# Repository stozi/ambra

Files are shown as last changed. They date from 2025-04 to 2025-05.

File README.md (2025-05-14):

# Ambra
A [Kalmar](https://github.com/aroum/kalmar)/[A. Dux](https://github.com/tapioki/cephalopoda/tree/main/Architeuthis%20dux)-based 34-key split ortho keyboard. [ZMK shield](https://github.com/stozi/zmk-keyboard-ambra)

### Included from Kalmar

- power switch
- reset button
- solder jumpers to mount the MCU the same way on both sides
- perforations on the tab for the connector between the right & left boards

### Changes from Kalmar

- thumb keys mount at 90° with pogo pins and 3D-printed magnet brackets
- besides Kailh Choc, support for Gateron KS-33, both hotswap only
- JST PH battery connector
- Switched the TRRS jack to the same pogo pin connector used for the thumb keys to prevent shorting (VCC/power is the middle pin so mounting one side backwards won't cause damage)
- ground plane for some ESD protection, new pinout

If you don't need fold-down packability or can't get the magnets, you can run a 9mm or longer M2 bolt through both brackets. However, any fall will then be more likely to cause damage.

Consider putting a non-conductive coating between the JST connector's mount points and the battery. Remove remnants of perforations on the thumb-key board before attaching the bracket. Personally, I solder the top-side jumpers to mount the MCUs component-side up so I can see the LEDs, and keep them safe under a case handcrafted from plumbing silicone.

Passed basic testing.

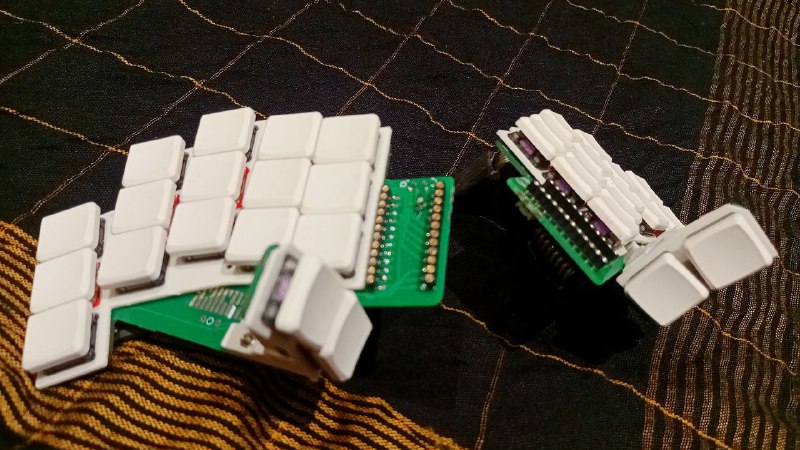
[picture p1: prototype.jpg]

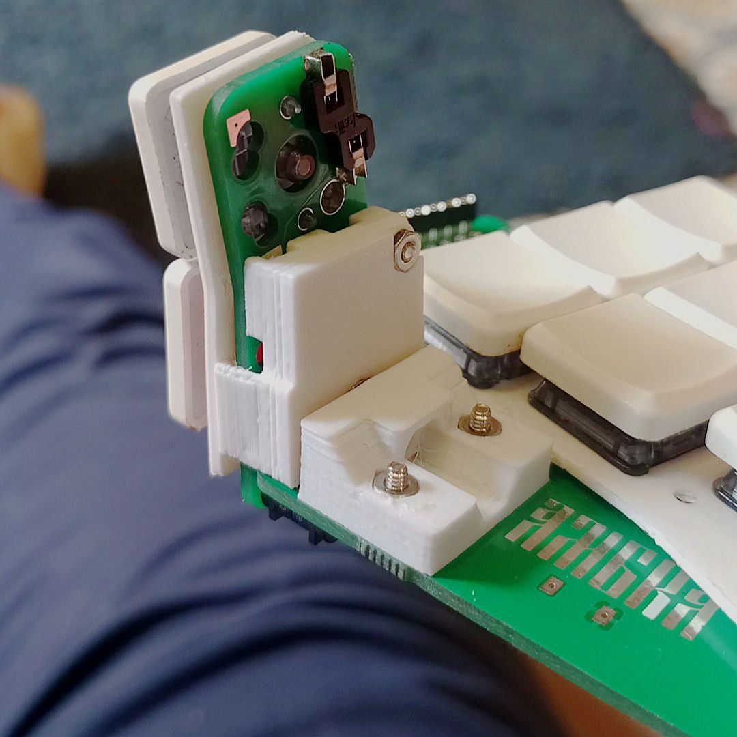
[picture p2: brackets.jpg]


## BOM

Item     | Qty   | Notes 
----------|-------|-------
[SuperMini NRF52840 MCU](https://www.aliexpress.com/item/1005008099333183.html) | 2 | inc. sockets. Alternatively, ProMicro/Elite-C for a wired build
[Kailh Choc V1](https://a.aliexpress.com/_EGNqHgc) | 34 | key switches. Alternatively, [Gateron KS-33](https://a.aliexpress.com/_EuUuYVU)
[Choc hotswap sockets](https://a.aliexpress.com/_Eu2JK5E) | 34 | Alternatively, [Gateron KS-33 hotswap sockets](https://a.aliexpress.com/_EGlN42e)
[Keycaps](https://a.aliexpress.com/_EGNqLfE) | 34 | 1U. If using KS-33 switches, STL files are provided to print your own 'MX stem, Choc-1U-spaced' caps
[Magnets](https://a.aliexpress.com/_EGMQ442) | 2 | D6×3mm annular cylinder
[RTLECS MG03254 3-pin](https://a.aliexpress.com/_Ev5QIZa) | 2 straight m, 2 90° f | magnetic pogo-pin connectors
[MSK-12CO2](https://aliexpress.ru/item/1005001398386692.html) | 2 | power switch
[SMD button 3×4×2](https://aliexpress.ru/item/1005003812819985.html) | 2 | reset switch
[301230 li-po](https://aliexpress.ru/item/32732458079.html) | 2 | battery
[JST PH right-angle 2-pin](https://www.aliexpress.com/item/1005008131930144.html) | 2 | battery connector
[JST wire](https://www.aliexpress.com/item/1005001649158434.html) | 2 | solder & shrink tube to battery wires, no crimping needed, or [battery already with connector](https://a.aliexpress.com/_EJkhjGm) 
[M3 machine screws, 3mm](https://www.aliexpress.com/item/1005006662972635.html) | 2 | flathead, couples with magnet
[M3 thin hex nuts](https://a.aliexpress.com/_EvCkuwM) | 2 |
[M2 tapered head machine screws, 7mm](https://a.aliexpress.com/_EzeQ9lA) | 2 | holds magnet
[M2 flat head machine screws, 8mm](https://www.aliexpress.com/item/1005006662972635.html) | 6 | for brackets
[M2 thin hex nuts](https://a.aliexpress.com/_EvCkuwM) | 8 |
OPTIONAL: [RTLECS MG03254 cable](https://www.aliexpress.com/item/1005007988032729.html) and extra RTLECS 90° female connectors as listed above | 2 of each | For a wired build: cut, solder and shrink-tube the two wires together

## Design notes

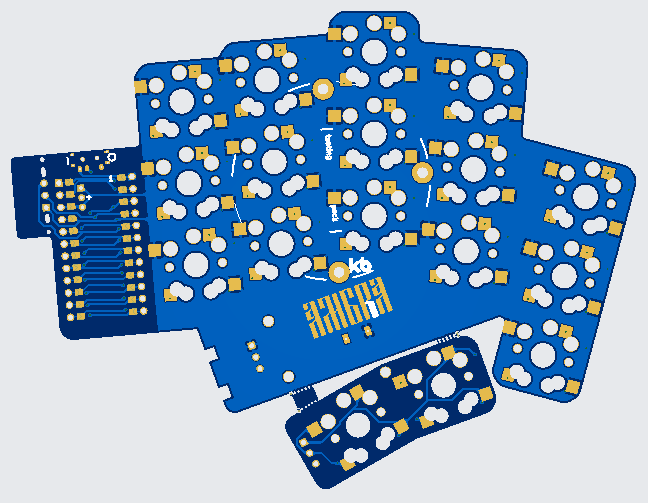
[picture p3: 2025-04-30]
ambra-back.png

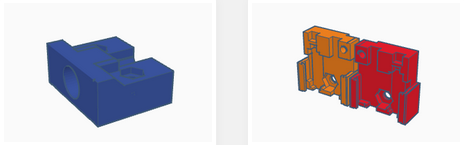
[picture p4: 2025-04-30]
brackets.png

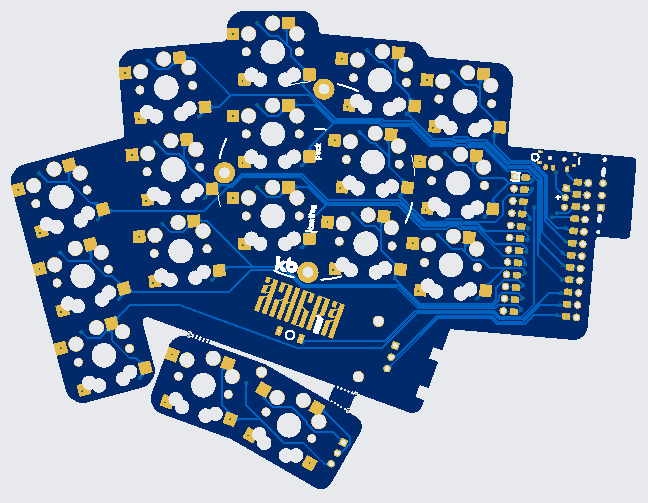
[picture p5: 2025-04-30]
ambra.png

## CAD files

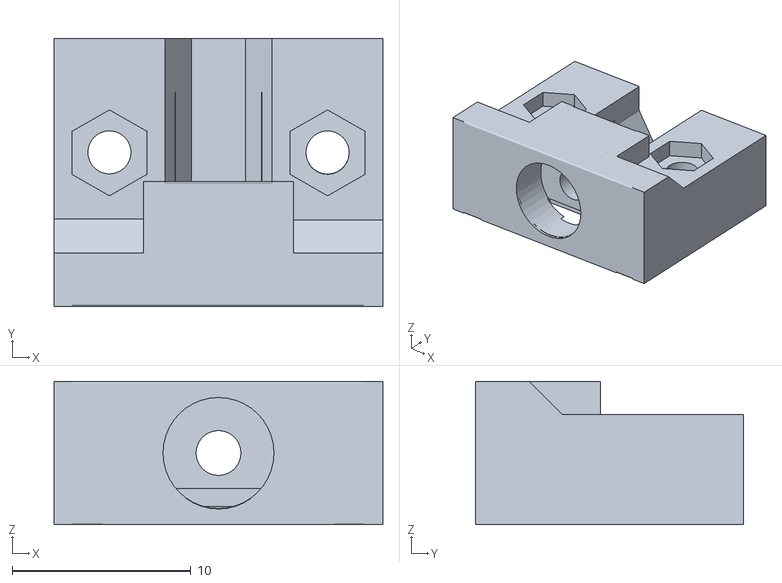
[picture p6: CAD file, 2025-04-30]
Ambra bracket board.stl
18.4 x 15.0 x 8.00

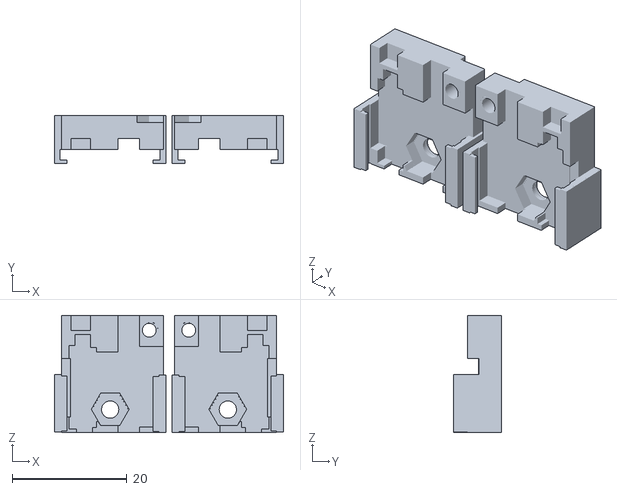
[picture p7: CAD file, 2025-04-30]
Ambra bracket thumb.stl
39.9 x 8.30 x 20.4

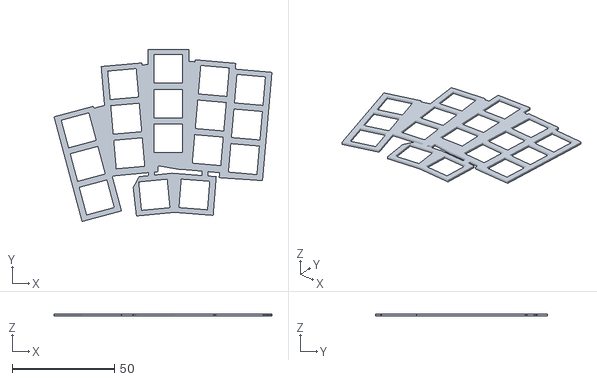
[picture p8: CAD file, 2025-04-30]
Ambra plate.stl
106.7 x 84.1 x 1.20

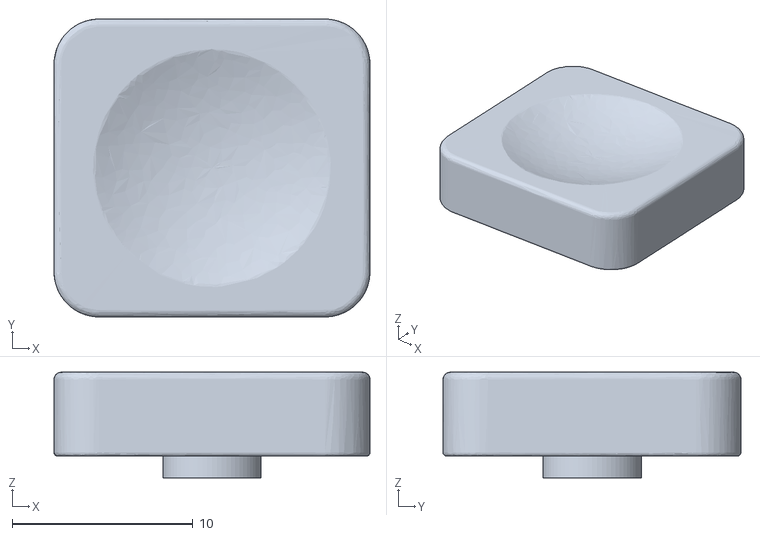
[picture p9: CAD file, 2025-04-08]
MX stem Choc U1.stl
17.5 x 16.5 x 5.85

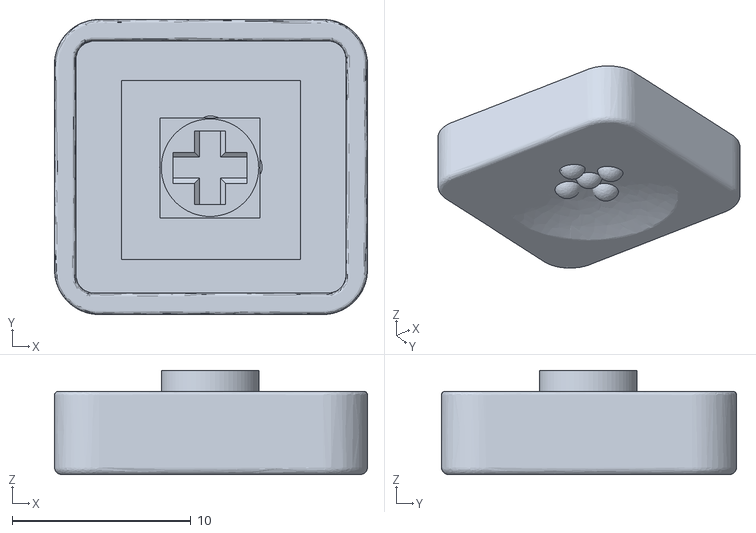
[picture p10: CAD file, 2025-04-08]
MX stem Choc U1 homing.stl
17.5 x 16.5 x 5.82

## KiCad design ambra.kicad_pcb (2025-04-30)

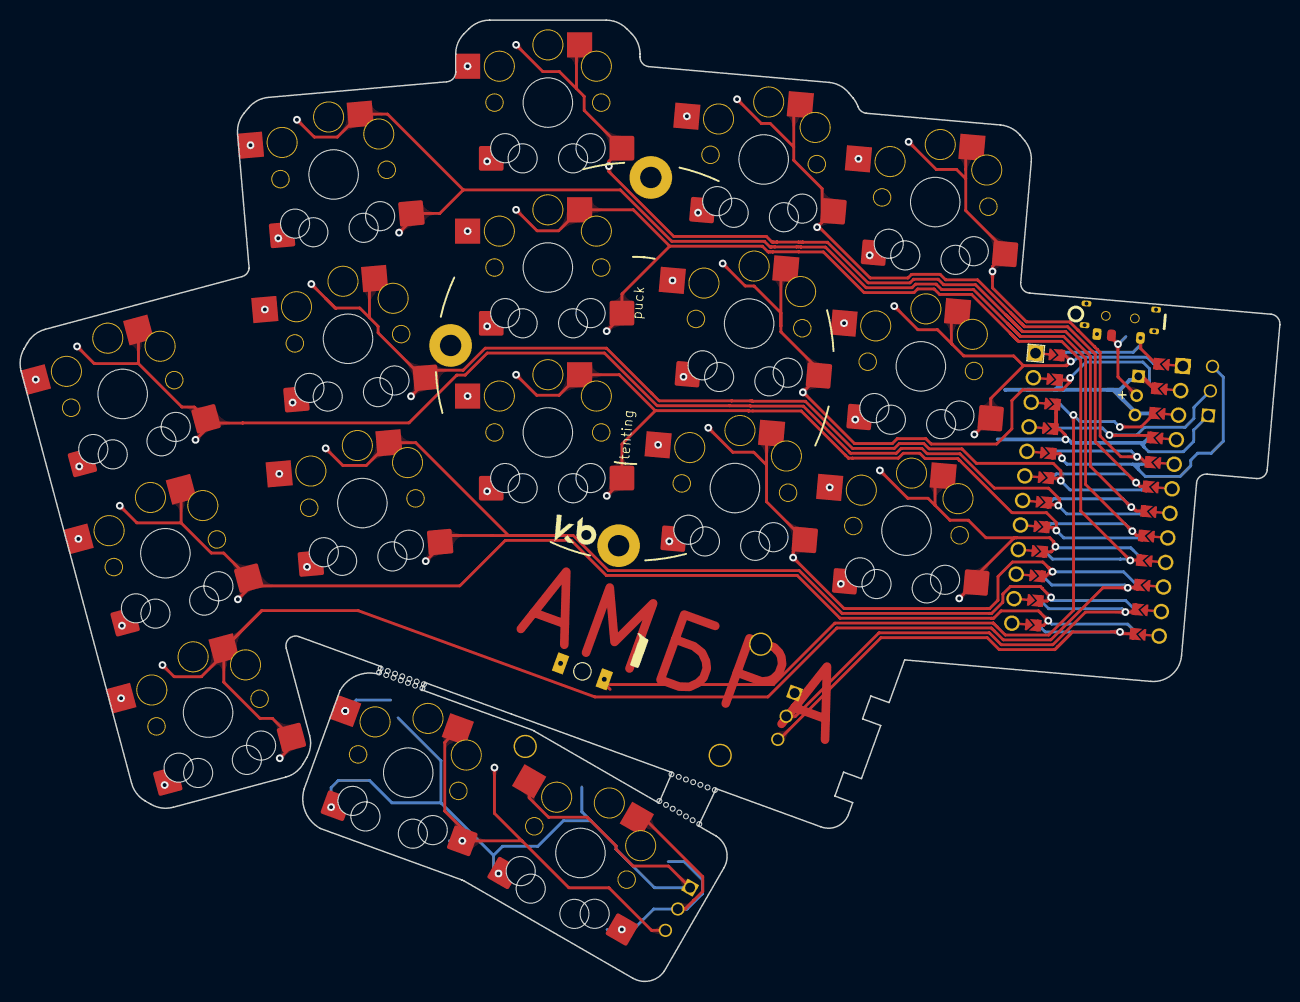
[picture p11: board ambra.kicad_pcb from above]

Board: 2 copper layers, 129.8 x 99.1 mm, 25 parts (1 on the bottom side), 21 nets.

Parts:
BT3, BT3#2, BT3#3, BT3#4: Breakaway Tabs; Breakaway_Tabs
H1: Hole; HOLE
RSW1: SW_PUSH; reset-SW_3x4x2_2legs_x2
SW1: SW_SPDT; switch_MSK-12C02_smd_x2_topor
SWr1c1, SWr1c2, SWr1c3, SWr1c4, SWr1c5, SWr2c1, SWr2c2, SWr2c3, SWr2c4, SWr2c5, SWr3c1, SWr3c2, SWr3c3, SWr3c4, SWr3c5, SWr4c1, SWr4c2: SW_PUSH; Choc-and-KS33-Hotswap-Choc-1U
U1: ProMicro_r; ProMicro_duplex_clean

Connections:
GND: RSW1.2, SWr1c1.1, SWr1c1.2, SWr1c2.1, SWr1c2.2, SWr1c3.1, SWr1c3.2, SWr1c4.1, SWr1c4.2, SWr1c5.1, SWr1c5.2, SWr2c1.1, SWr2c1.2, SWr2c2.1, SWr2c2.2, SWr2c3.1, SWr2c3.2, SWr2c4.1, SWr2c4.2, SWr2c5.1, SWr2c5.2, SWr3c1.1, SWr3c1.2, SWr3c2.1, SWr3c2.2, SWr3c3.1, SWr3c3.2, SWr3c4.1, SWr3c4.2, SWr3c5.1, SWr3c5.2, U1.3 (GND), U1.4 (GND), U1.23 (GND)
GND2: SWr4c1.1, SWr4c1.2, SWr4c2.1, SWr4c2.2
VBAT: SW1.1 (A), U1.24 (RAW)
db1: SWr4c1.1, SWr4c1.2
db2: SWr4c2.1, SWr4c2.2
r1c1: SWr1c1.1, SWr1c1.2, U1.20 (A3/F4)
r1c2: SWr1c2.1, SWr1c2.2, U1.19 (A2/F5)
r1c3: SWr1c3.1, SWr1c3.2, U1.18 (A1/F6)
r1c4: SWr1c4.1, SWr1c4.2, U1.17 (A0/F7)
r1c5: SWr1c5.1, SWr1c5.2, U1.7 (D4/4)
r2c1: SWr2c1.1, SWr2c1.2, U1.1 (D3/TX0)
r2c2: SWr2c2.1, SWr2c2.2, U1.2 (D2/RX1)
r2c3: SWr2c3.1, SWr2c3.2, U1.16 (15/B1)
r2c4: SWr2c4.1, SWr2c4.2, U1.6 (SCL/D0/3)
r2c5: SWr2c5.1, SWr2c5.2, U1.12 (B5/9)
r3c1: SWr3c1.1, SWr3c1.2, U1.9 (D7/6)
r3c2: SWr3c2.1, SWr3c2.2, U1.10 (E6/7)
r3c3: SWr3c3.1, SWr3c3.2, U1.8 (C6/5)
r3c4: SWr3c4.1, SWr3c4.2, U1.11 (B4/8)
r3c5: SWr3c5.1, SWr3c5.2, U1.15 (14/B3)
reset: RSW1.1, U1.22 (RST)
